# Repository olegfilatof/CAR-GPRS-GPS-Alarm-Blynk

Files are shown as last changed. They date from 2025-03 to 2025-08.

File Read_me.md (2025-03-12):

 Представляю Вашему вниманию «автомобильная сигнализация с функциями удалённого контроля и позиционирования авто». 
 Основные возможности: 
1. Первичные настройки и  контроль за параметрами осуществляются при помощи веб интерфейса, в который можно попасть, используя подключение к Точке Доступа (далее ТД) подключившись к точке доступа MY_AVTO-WIFI, возникающей через 20 сек после подключения питания 12VDC от автомобильного аккумулятора.
2. Основные параметры:
	а) Напряжение аккумулятора, по которому косвенно и сильно не точно можно судить 	о заряде аккумулятора
	б)  Температура в салоне, температура двигателя. 
	в) Координаты GPS авто (необходимо около 10 мин для «холодного старта» при 		    первом запуске устройства)
	г) Состояние датчика вибрации (возможно использование вместо него датчика 		   Холла, герконов, конечных выключателей и т. д., допускается множество 	  		    параллельно соединённых датчиков с NO контактами, с замыканием контактов при 	    срабатывании).
	д) Состояние инфракрасного датчика присутствия  SR505, с задержкой замкнутых 		контактов при срабатывании на  10 сек., для инвертирования сигнала, по требованиям  	правильной 	логики работы устройства, применен обычный маломощный NPN 	транзистор, см. схему. Параллельно допускается использование других датчиков с NO 	контактами, с замыканием контактов при срабатывании).
	е) Состояние двух реле для контроля авто дистанционно. Первое рекомендуется 	применять для аварийной остановки авто, разрывая любые важные для 	функционирования цепи: бензонасос, управление меткой электронного ключа, цепи 	шины CAN и т. д. Контакты второго реле рекомендуется подключить к 	автомобильному клаксону, время работы = 1 мин, с автоматической остановкой. 
	ж) Включатель работы GPS, модема GPRS. 
	з) Изменение пароля ТД 
	и) Изменение периода работы модема, это время паузы между выходами модема на 	     связь. 
	к) Настройка apn sim карты для успешного соединения с сетью Internet. 
Каждое действие в меню обязано завершаться кликом на «Перегрузить устройство с сохранением». 
 Не удалось организовать динамический ввод
 //#define BLYNK_TEMPLATE_ID "jhj"
//#define BLYNK_TEMPLATE_NAME "kgkhjgk"
//#define BLYNK_AUTH_TOKEN "jjh"
так как это противоречит условиям Blynk API.  Кому удастся- прошу дать мне знать об этом. Пользователь обязан вставить свои параметры в код самостоятельно, выбрав в Blynk при создании устрйства: «ESP32» и способ соединения: GSM. 
Логика работы устройства следующая: при подаче питания впервые, начинает через 20 секунд работать ТД. После окончания необходимых настроек, пользователь нажимает «Перегрузить устройство с сохранением». 
После этого включается единственный раз на 2 минуты, - первый запуск после любого Reboot, - ТД с Вашим паролем, сохранённым в контроллере после ввода пользователем. 
 Через 2 мин wifi отключается и запускается модем. 

  Далее вся работа с сигнализацией ведётся через великолепное приложение Blynk, разработанный  украинскими гениями. 
 Мне удалось на бесплатном аккаунте добиться вывода полученных дистанционно координат на карте в браузере, по клику, во всём инете не встречал подобного, одни вопли о 100$ за такую возможность на платном аккаунте.
 После подключения к Blynk и успешного соединения модема с облачным сервисом, в меню Blynk появляются данные. Имеется возможность управления дистанционно. 
 После успешной передачи данных контроллер и вся система уходят в глубокий сон, с энергопотреблением в районе  2 микроампера. Для сравнения, обычная сигнализация без доступа по сети интернет, в стерегущем режиме потребляет около 25mA, на три порядка (!) больше. 
 Время выхода на связь можно задать и из меню Blynk. Рекомендуется 30 — 180 минут. 
В режиме «коннект каждые 30 минут» не удалось выйти за лимит 30000 сообщений бесплатного аккаунта blynk в месяц. Не рекомендуется устанавливать слишком малый интервал из-за высокого энергопотребления модема и неоправданного расхода батареи авто. 
  Привет  тебе, погромист  с  народным платным проектом "GSM автосигнализация" https://www.drive2.ru/c/593248096910065300/ с двумя(!) контроллерами :) и потреблением 150- 200mA постоянно… На мой взгляд, сигнализация, высаживающая заряд автомобильного аккумулятора за неделю  стоянки, — это уже за гранью добра и разума.  
 Не забыты и странные жители тоталитарных стран, с тотальным воровством у ближнего и, как следствие, наличием дополнительной сигнализации в каждом(!) авто. Поэтому предусмотрен аварийный выход из режима сна и выход на связь — при аларме, вызванном срабатыванием любого из сенсоров. При этом каждые 30 сек в течении 2-х минут высылаются  параметры, связанные с охраной авто. Включаются алармы обычной кнопкой при выходе из авто. И я и супруга за ненадобностью такой опции, регулярно забываем о кнопке, да оно и не надо в нормальных странах совершенно… А вот точка на карте, где оставили авто при путешествиях — просто бесценная информация. Вспоминаю, как мы осенью искали час авто без GPS датчика в Праге… :)
 Уведомления о событиях элементарно настраиваются в Blynk, раздел «автоматизация»,  начиная со звукового сигнала в режиме реального времени о событии и заканчивая посылкой сообщения на e-mail. 
 Предложения по усовершенствованию кода, улучшениях в логике работы, благодарностях — приветствуются. 
Disclaymer:  код и схема устройства предоставляются под свободной лицензией и любые претензии к Автору по поводу убытков и неудобств, вызванных попытками изготовления и  использования данного устройства, являются юридически несостоятельными. Автор снимает с себя всякую ответственность за возможные неудобства, материальные убытки и последствия из-за использования продуктов его интеллектуального труда. Ссылка на код, чертежи, промышленное изготовление Устройства возможны  только на условиях  упоминания моего авторства. Искренне Ваш, Олег Филатов. 

Список использованных устройств: 
1. контроллер esp32 Wroom — 1шт. (примерная стоимость 4 Euro
2. DC-DC преобразователь 12VDC- 5VDC, 2A, примерная стоимость 1 Euro
3.  модем SIM800C, выбирайте с питанием 5V только!! И TTL согласованием Rx Tx на плате,  примерная стоимость 3.5 Euro
4. GPS модуль  Neo-6MV2, 3.5 Euro
5. Датчик инфракрасный  SR505, 1 Euro
6. Выключатель алармов, 1 Euro
7. транзистор npn 2N4401, либо любой другой, маломощный NPN транзистор 0.5 Euro
8. 2 транзистора MOSFET IRLB8743, либо другие, надёжно открывающиеся от напряжения выше 2.5VDC (напряжение порта используемого контроллера 3.5VDC) и ток не менее 5A.,
- 2 Euro
9. Резисторы номиналов: 10k — 4шт, 1к -1 шт, 1M — 1 шт, 220К — 1 шт. = 0.5 Euro
10. Реле для Ардуино, 5В — 2 шт, Level HIGH,  2 Euro
11. Датчики DS18B20, Dallas, гильзованные — 2 шт, 2 Euro
12. Геркон с магнитом, 1 шт. — 1E.
Итого: примерно 20 Евро за автосигнализацию с интернет доступом. 
 Для сравнения: средняя сигнализация для авто, с локальным управлением, стоит около 100Euro, с GSM модулем- от 200Euro. Минус удовольствие от творчества… :). 

    1. Лайфхак от меня. Прикупить esim sim карту, самую простую, даже с ограничением на установку только 2-х профилей, например: 5ber, либо 9esim. 
       Находим контору, дающую esim прямо при регистрации, например Betterroaming 
    2. Оплачиваем профиль «Europe Global» за пару евро на год, 1Гб трафика. 
    3. Вставляем в модем, прописываем apn- всё, за символические средства мы видим авто в любой точке Европы целый год. Можно вообще не экономить батарею и настроить систему работать без отключений и сна. Но это уже путь мазохиста- экспериментатора. Алло, мы ищем таланты и отзывы от них! 

Тарифы, к примеру:  esim  от  bnesim на сегодня. Роскошно же. 

Surf 1GB in Europe
1GB
Validity: ∞
No expiry
$2.28
(€2.10)

    Дарю код бесплатно, принимаю благодарности в евро на счёт с реквизитами IBAN:
	 BE95 9741 1406 6858, Oleg Filatov. Bank ID code: PESOBEB1.

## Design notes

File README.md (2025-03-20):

# CAR-GPRS-GPS-Alarm-Blynk
Car alarm remote system with wifi local settings and Blynk web interface. 
 Connection: gprs modem SIM800C. 
 Coordinates: GPS transmitter. 
 Alarms: 2 sensors, InfraRed Human and Vibro sensor.
 Control: 2 relays. Control equipment: motor stop and sound alarm.
 extra sensors: any, NO contacts in parallel with vibro and IR sensors.
 Power supply: 12-14.5VDC from car accumulator battery.
 Power consumption: 0.1 A/h per day. Don't worry about your battery life!
  Connect all electronic elements in accordance with drowings and flash 
  controller. 2 Hours- and you will get 20Euro auto alarm with GPS positioning 
  and controls. Good Luck!

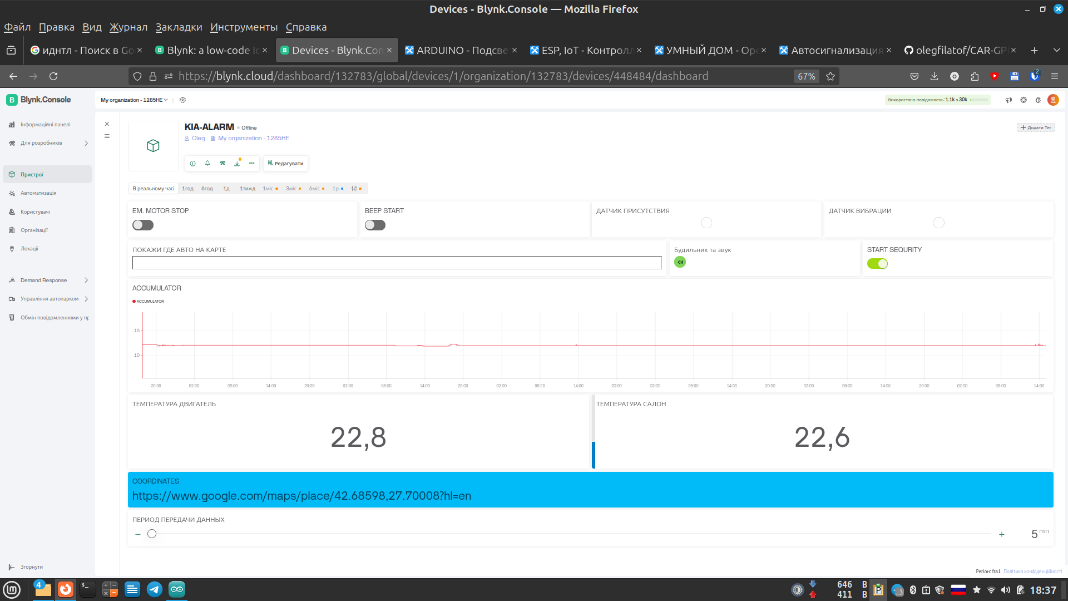
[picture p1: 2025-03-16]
Blynk-full.png

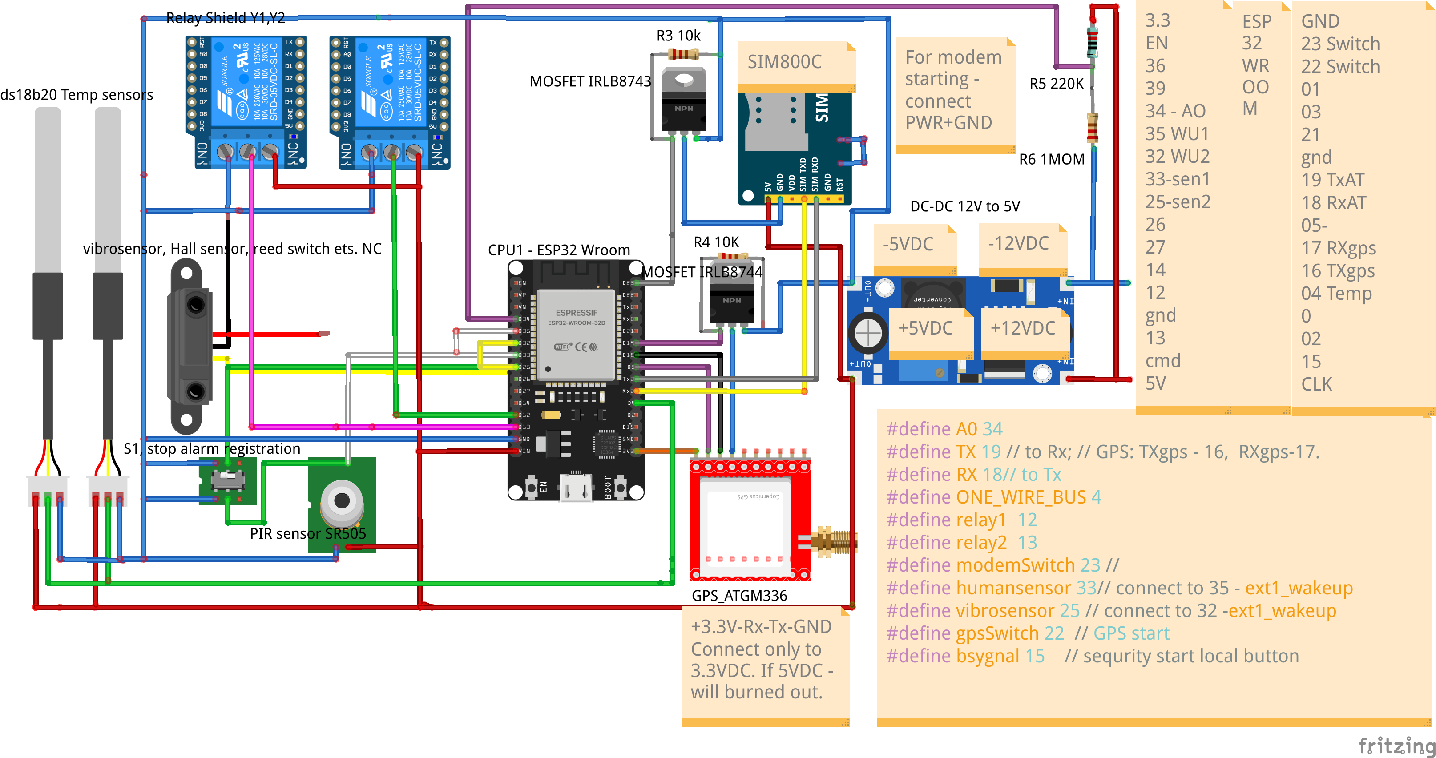
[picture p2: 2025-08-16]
AvtoAlarm_МП.png

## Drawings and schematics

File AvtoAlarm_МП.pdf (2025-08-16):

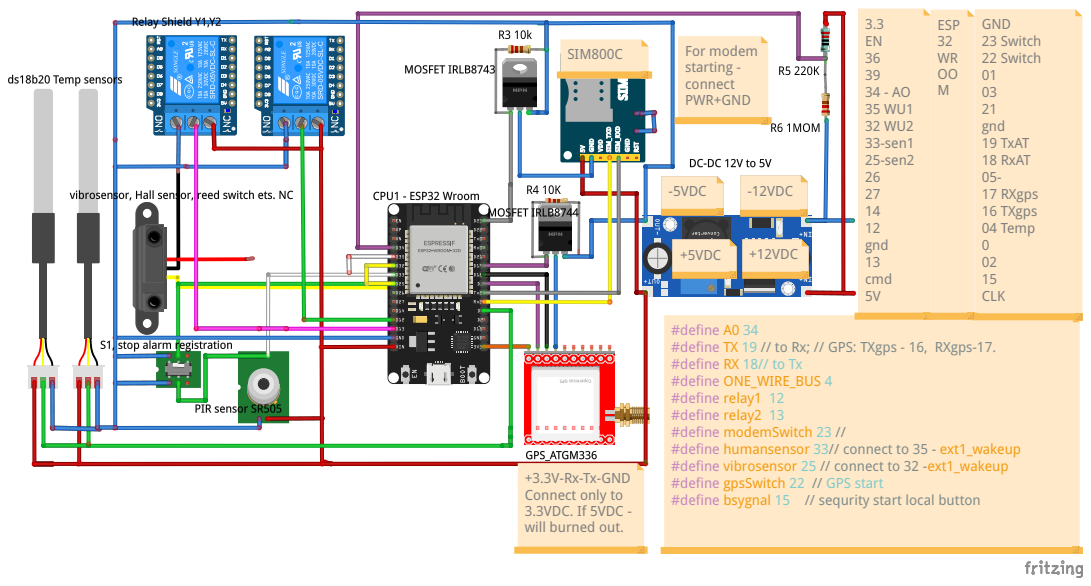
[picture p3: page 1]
For modem starting - connect PWR+GND; -5VDC; 3.3 EN 36 39 34 - AO 35 WU1 32 WU2 33-sen1 25-sen2 26 27 14 12 gnd 13 cmd 5V; GND 23 Switch 22 Switch 01 03 21 gnd 19 TxAT 18 RxAT 05- 17 RXgps 16 TXgps 04 Temp 0 02 15 CLK; ESP 32 WR OO M; +12VDC; -12VDC; +5VDC; SIM800C

#define A0 34
#define TX 19 // to Rx; // GPS: TXgps - 16, RXgps-17.
#define RX 18// to Tx
#define ONE_WIRE_BUS 4
#define relay1 12
#define relay2 13
#define modemSwitch 23 //
#define humansensor 33// connect to 35 - ext1_wakeup
#define vibrosensor 25 // connect to 32 -ext1_wakeup
#define gpsSwitch 22 // GPS start
#define bsygnal 15 // sequrity start local button

+3.3V-Rx-Tx-GND
Connect only to
3.3VDC. If 5VDC -
will burned out.

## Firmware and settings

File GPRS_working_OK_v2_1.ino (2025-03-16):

//OK for ESP32 Dev Module
/* Comment this out to disable prints and save space */
#define BLYNK_PRINT Serial
//-----------------------------------------------------------------------
#define BLYNK_TEMPLATE_ID           "TMPL4fa-kn3Dz"
#define BLYNK_TEMPLATE_NAME         "CAR GPS"
#define BLYNK_AUTH_TOKEN            "HDl45JpsYRZgO3nOyNjqZLBxPqDeuFlx"
// You should get Auth Token in the Blynk App.
// Go to the Project Settings (nut icon).
//char auth[] = BLYNK_AUTH_TOKEN;
//============================================

bool modemStartingF = false;
int sleepTime = 3; // для задачи периода сна, в минутах!!!
bool firstTime = true; // флаг для однократного запуска wifi в 1-й раз

//============================================

#include "initiation.h"
#include "settingsInit1.h"
bool sequrityStart = true; // по умолчанию охрана включена
static bool flag = false;

void SendData() {
  if (alarmON and sequrityStart) {
  //если выходит на связь по программе- отправлять 1 раз координаты, voltage, temperatures. Если сработал alarm- 
  // каждые 30 сек высылается состояние датчиков в течении 3 мин 
    Blynk.virtualWrite(V20,alarmHF);
    Blynk.virtualWrite(V21,alarmVF);
    Blynk.virtualWrite(V13,alarmON); //звуковой сигнал
    //Blynk.virtualWrite(V13,alarmON); //звуковой сигнал
     //  coordinates = "https://www.google.com/maps/place/"+String(latitude,8)+","+String(longitude,8)+"?hl=en";
 // url = "https://www.google.com/maps/place/"+String(latitude,6)+","+String(longitude,6)+"?hl=en"; //ОК
         // real GPS////////////
      gps.read();
  url = "https://www.google.com/maps/place/"+String(gps.latitude,5)+","+String(gps.longitude,5)+"?hl=en"; //ОК 
//////////////////////

  Blynk.virtualWrite(V7, url); // Отправляем динамический URL на V7
  Blynk.virtualWrite(V27, flag); // Отправляем динамический URL на V27
  Blynk.setProperty(V27, "url", url);
  Serial.print("Отправил данные алармов из SendData, alarmHF=   "); Serial.println(alarmHF); 
  Serial.print("Отправил данные алармов из SendData, alarmVF=   "); Serial.println(alarmVF); 
  }}
  

void setup()
{
  // Debug console
  Serial.begin(115200);

  // используем метод ext1 для пробуждения по уровню на портах, понадобится вот эта строчка: 
  esp_sleep_enable_ext1_wakeup(pinBitMask,ESP_EXT1_WAKEUP_ANY_HIGH);
//  ESP_EXT1_WAKEUP_ALL_LOW: wake up when all GPIOs go low; - если ВСЕ порты... 
//  ESP_EXT1_WAKEUP_ANY_HIGH: wake up when any of the GPIOs go high. -любой порт из указанных
//If you’re using an ESP32-S2, ESP32-S3, ESP32-C6 or ESP32-H2, these are the available modes:
//ESP_EXT1_WAKEUP_ANY_LOW: wake up when any of the selected GPIOs is low
//ESP_EXT1_WAKEUP_ANY_HIGH: wake up when any of the selected GPIOs is high

  pinMode(relay1,OUTPUT);
  pinMode(relay2,OUTPUT);
  pinMode(modemSwitch,OUTPUT);
  pinMode(gpsSwitch,OUTPUT);
  pinMode(humansensor,INPUT_PULLUP); humansensorI.setDebounceTime(50);
  pinMode(vibrosensor,INPUT_PULLUP); vibrosensorI.setDebounceTime(50); 
  //pinMode(bsygnal,OUTPUT);  bsygnalI.setDebounceTime(50); 
//после выхода из сна ножка (ножки) IO, которая используется для пробуждения, может быть сконфигурирована как RTC IO. 
//Перед использованием этой ножки в качестве digital GPIO переконфигурируйте её с помощью функции rtc_gpio_deinit.
  
  digitalWrite(relay1,0);
  digitalWrite(relay2,0);
  digitalWrite(modemSwitch,0);
  digitalWrite(gpsSwitch,0);
  //digitalWrite(2,0); 
  pinMode(intLed,OUTPUT);
  digitalWrite(intLed,0); // onboard LED stop

  delay(10);

#include "setup1.h"
#include "settingsSetup2.h"
////////////////////////////////////////////////////////////////////////////////////////////////////////////


startGPSF = db[dataBase::startGPS]; // флаг включения GPRS
   // узнаём, в каком состоянии переменные в базе данных:
   // если строка с APN заполнена - читаем оттуда apn, иначе - смотри строку 37 initiation.h, там якобы универсальный APN 
if (db[dataBase::sim_APN].length()) { apn = db[dataBase::sim_APN].toString(); } // кому не нравятся тут {} - может удалить самостоятельно, я не возражаю :)


//if (db[dataBase::GPS_interval_send].length()) {sleepTime = db[dataBase::GPS_interval_send].toInt64(); } // интервал в микросекундах, загрёбся я переводить эту хрень в нужный формат... 
// else {sleepTime = 30;} // 30 минут - интервал выхода на связь и посылка данных в blynk, если режим экономии батареи
sleepTime = db[dataBase::GPS_interval_send].toInt64(); 
relay1F = db[dataBase::engineStop];
relay2F = db[dataBase::beepStart];
batteryF = db[dataBase::saveBattery];

  
/////////////////////////////////////////////////////////////// 

  // вызываем таймер отправки в blynk по времени if (wifiStart1time) { wifiStart1time = false; Wificonnection(); } 
  timer.setInterval(INTERVAL, SendData);
  //-----------------------------------------------------------  
///////////////////////////////////////////////////////////////
 /*
  wifiStart1time = true;
  if (wifiStart1time) // исли 1-й раз стартуем - старт wifi,  wifiStart1time == true
  { if (startGPSF) {TimerModemStart.start();} // если включён GPRS в настройках- старт модем через 2 мин после старта wifi
  
  // если нет - wifi продолжает работать всё время и аккамулятору капут через неделю
  
  { wifiStart1time = false;  Wificonnection();  } 
  }
  // если это уже второй запуск, после сна, то wifi не включается, а сразу модем, без паузы на wifi:
  else { WifiStop(); ModemStart(); modemStartingF = true; TimerModemStop.setTimeout(120000);}
  
  // если не нажато "Старт GPS, стоп wifi, экономим заряд батареи", то wifi не отключает соединение, модем не стартует, в сон не впадаем
//даём wifi подключиться, затем таймер сработает- и пипец тому wifi, GPRS рулит необычвйно

 //если включён старт gprs в settings морде- стартуем модем через 120 сек и стоп wifi если 1-й запуск,
 //если запуск после сна - стразу старт модем. 
*/

if (startGPSF and wifiStart1time) { TimerModemStart.setTimeout(120000); } // в первый раз - пауза на работу wifi 2 min, затем- модем, если включён в настройках

if (startGPSF and wifiStart1time == false) { ModemStart(); modemStartingF = true; TimerModemStop.setTimeout(120000);} //Если не 1-й раз - модем запускаем сразу 

if (wifiStart1time) { Wificonnection(); loopData = true; } // запускаем в первый раз, потом включается wifiStart1time = false; в функции
// если заснёт -  усё, потом нет wifi-я, зая!. Если перезагрузить - ок, wifi первые 2 минуты + web морда вайфайная, либо wifi всегда, если не запущен GPS в вэбморде

// включаем через 2 минуты модем, если включён в web морде startGPS, выключается автоматически  wifi.
// иначе - пипец заряду аккумулятора через 10 дней, привет тебе, погромист,
// с проектом "GSM автосигнализация" https://www.drive2.ru/c/593248096910065300/ с двумя(!) контроллерами :) и потреблением 150mA постоянно...

//-----------------------------------------------------------
 // Serial.print("startGPSF = " ); Serial.println(startGPSF);
 // Serial.print("apn = " ); Serial.println(apn);
 // Serial.print("sleepTime = " ); Serial.println(sleepTime);
 // Serial.print("relay1F = " ); Serial.println(relay1F);
 // Serial.print("relay2F = " ); Serial.println(relay2F);
 // Serial.print("batteryF = " ); Serial.println(batteryF);
 // Serial.print("wifiStart1time = " ); Serial.println(wifiStart1time);
 //Serial.print("sequrityStart = " ); Serial.println(sequrityStart);
}
 
/**********************************************************************************
 *  loop() function
 **********************************************************************************/
void loop()
{
  
  if (TimerModemStart.isReady()) { WifiStop(); loopData = false; ModemStart(); modemStartingF = true; TimerModemStop.setTimeout(120000);}  

  if (modemStartingF) { Blynk.run();  timer.run();  }
     
  if (TimerModemStop.isReady()) { modemStartingF = false; ModemStopping();  } //Serial.println("сработал таймер сна ");
  
  sett.tick(); //3 settings in loop
  
  #include "loop3.h"

/*
    static unsigned long timerGPS;
  if (millis() - timerGPS >= 2000) {
    timerGPS = millis();
       gps.read();
  url = "https://www.google.com/maps/place/"+String(gps.latitude,5)+","+String(gps.longitude,5)+"?hl=en"; //ОК 
  Serial.println(url);
  }
*/
}
//////////// Лупец finish ///////////////////////////////////////////////
 
 BLYNK_WRITE(V1) // From Blynk to the ESP32, to control a Relay1
  {
  int pinValue1 = param.asInt();
  digitalWrite(relay1 , pinValue1);
  
  }
     BLYNK_WRITE(V2) // From Blynk to the ESP32, to control a Relay2
  {
  int pinValue2 = param.asInt();
  digitalWrite(relay2 , pinValue2); 
  }

       BLYNK_WRITE(V3) // From Blynk to the ESP32, to control a Relay2
  {
  int sequrityStart = param.asInt(); // assigning incoming value from pin V1 to a variable
  
  }

  BLYNK_WRITE(V28)
  {
  int sleepTime = param.asInt(); // assigning incoming value from pin V1 to a variable
  // You can also use: String i = param.asStr();  double d = param.asDouble();
  //Serial.print("V28 Slider value is: ");
  //Serial.println(sleepTime);
  db[dataBase::GPS_interval_send] = sleepTime; db.update(); // ХЗ, с этими update, никогда не удавалось с ходу понять логику Gyver... :)
  }

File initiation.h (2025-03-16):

#include "GyverTimer.h"              // библиотека таймера
//Timer Timer1month(MS, 2592000000); // (86400000×30 суток)ms для однократного срабатывания
GTimer TimerModemStart(MS); // 
GTimer TimerModemStop(MS); // 

GTimer Timer2minWIFI(MS); // cтоп wifi после 2 мин. работы
GTimer Timer3minModemON(MS); //время работы модема

GTimer Timer1minH(MS); // сработал датчик human - 1 мин аларм
GTimer Timer1minV(MS); // сработал датчик vibro - 1 мин аларм

GTimer Timer30sec1(MS); // сработала кнопка stop motor - 30 сек аларм
GTimer Timer30sec2(MS); // сработала кнопка старт бибикалка - 30 сек аларм

//GTimer Timer1sec(MS);

//TimerModemStart.setTimeout(120000);   // настроить таймаут 120 сек и запустить (перезапустить) таймер
//if (TimerModemStart.isReady()) Serial.println("Timeout 120сек сработал!");
//TimerModemStart.stop();   // "остановить" таймер
//myTimer.setTimeout(3000);   // настроить таймаут 3 сек, затем - стоп без условий
//----------------------------------------------------------------------
#define VREF 1.0328 // VREF = 1.1V в ESP32, но тут надо с вольтметром в руках прикидывать поправку, от множества факторов зависят измерения, 
// причём, слухи о "лютой нелинейности АЦП esp" - неуместны. :).
// 1.04 - 12.00; 1.034 - 11.94; 1.032 - 11.90

// Измерение Напряжения
// GND -- [ R2 ] -- A0 -- [ R1 ] -- VIN  + 0.1 mkF конденсатор на GND и порт A0
#define DIV_R1 1000000  // точное значение 1000 кОм резистора (1 MOM)
#define DIV_R2 220000   // точное значение 220 кОм резистора

#define A0 34 // Это порт аналогового сигнала от делителя напряжения аккумулятора
//----------------------------------------------------------------------
// Select your modem:
#define TINY_GSM_MODEM_SIM800
//#define TINY_GSM_MODEM_SIM900

//-----------------------------------------------------------------------
// Default heartbeat interval for GSM is 60
// If you want override this value, uncomment and set this option:
#define BLYNK_HEARTBEAT 185 // больше времени соединения, чтоб не пересоединялся каждые 30 сек
//-----------------------------------------------------------------------
#include <TinyGsmClient.h>
#include <BlynkSimpleTinyGSM.h>
//-----------------------------------------------------------------------
// Your GPRS credentials
// Leave empty, if missing user or pass
String (apn) = "internet";
char user[] = "";
char pass[] = "";
//-----------------------------------------------------------------------
#include <iarduino_GPS_NMEA.h>                     //  Подключаем библиотеку для расшифровки строк протокола NMEA получаемых по UART.
#include <iarduino_GPS_ATGM336.h>                  //  Подключаем библиотеку для настройки параметров работы GPS модуля ATGM336.
                                                   //
iarduino_GPS_NMEA    gps;                          //  Объявляем объект gps         для работы с функциями и методами библиотеки iarduino_GPS_NMEA.
iarduino_GPS_ATGM336 SettingsGPS;                  //  Объявляем объект SettingsGPS для работы с функциями и методами библиотеки iarduino_GPS_ATGM336.
/////////////////////////////////////////////////////////////////////////////////////////////////////////
//Modem:
#define RXmodem 18 // 
#define TXmodem 19 // 

//GPS
#define RXgps 17 //
#define TXgps 16 //   
#define GPS_BAUD 9600  // обязательно.  на скорости 115200 - не работает!

HardwareSerial gpsSerial(1);
HardwareSerial SerialAT(2);
#define gpsSerial Serial1
#define SerialAT Serial2


TinyGsm modem(SerialAT);
//TEMPERATURE SENSORS-----------------------------------------------------
#include <OneWire.h>
#include <DallasTemperature.h>
// Setup a oneWire instance to communicate with any OneWire devices
#define ONE_WIRE_BUS 4
OneWire oneWire(ONE_WIRE_BUS);
// Pass our oneWire reference to Dallas Temperature sensor 
DallasTemperature sensors(&oneWire);
//________________________________________________________________________
#define intLed 2 // светодиод blue onboard, надо погасить, шоб не ел ток аккумулятора
#define relay1  12
#define relay2  13
#define modemSwitch 23 // выключатель модема
#define humansensor 33 // объединить с 35
#define vibrosensor 25 // объединить с 32 
//#define bsygnal 15// сигнал с сервера о постановке на охрану, pin V3 на сервере, либо физически замкнута кнопка T1
#define gpsSwitch 22 // выключатель GPS
//----------
float temp1; // pin 4
float temp2; // pin 4
//float longitude;
//float latitude; 
String coordinates;
int humanSt = 0;
int vibroSt = 0;
bool alarmHF; 
bool alarmVF;
//int bsygnalSt = 0;
bool alarmON = false;
String Temp1;
String Temp2;
float voltage;
bool sequrityStartF;
String url;
bool loopData;
// Save reading number on RTC memory
RTC_DATA_ATTR bool wifiStart1time = true;  // смотри функцию Wificonnection() { if (wifiStart1time) {wifiStart1time = false;} 
//-----------------------------------------------------------------------
BlynkTimer timer;
#define INTERVAL 30000L // интервал отправки данных при подключенном модеме
//-----------------------------------------------------------------------

//#define humanSensor  39 // датчик присутствия // уже указан в маске 35
//#define vibroSensor  34 // датчик вибрации   // уже указан в маске  32

//////////////////////////
//Режим глубокого сна и внешнее пробуждение
//В качестве инициатора внешнего пробуждения могут использоваться только контакты типа RTC_GPIO. Вот они: 
//ESP32: 0, 2, 4, 12-15, 25-27, 32-39 //ESP32-S2: 0-21 //ESP32-S3: 0-21 //ESP32-C6: 0-7 //ESP32-H2: 7-14

// Пробуждение, если любая из выбранных ножек находится в лог. 1 (ESP_EXT1_WAKEUP_ANY_HIGH).
// Пробуждение, если любая из выбранных ножек находится в лог. 0 (ESP_EXT1_WAKEUP_ALL_LOW).
//сделал битовый флаг не как у индуса, с маятой и мутью, а грамотно: 
int WakeUppin, wakeFlag = 0;
constexpr uint8_t humanSensor = 35;
constexpr uint8_t vibroSensor = 32;
constexpr uint64_t humanSensorBitFlag = (static_cast<uint64_t>(1) << humanSensor);
constexpr uint64_t vibroSensorBitFlag = (static_cast<uint64_t>(1) << vibroSensor);
constexpr uint64_t pinBitMask = (humanSensorBitFlag | vibroSensorBitFlag);
void print_GPIO_wake_up(){
   WakeUppin = log(esp_sleep_get_ext1_wakeup_status())/log(2);
  Serial.print("WakeUppin = "); Serial.println(WakeUppin); 
  if (WakeUppin == humanSensor) {  wakeFlag = 1; Serial.println("Сработал humanSensor");}
  if (WakeUppin == vibroSensor) {  wakeFlag = 2; Serial.println("Сработал vibroSensor");}
 // if (WakeUppin == newSensor) {  wakeFlag = 3; Serial.println("Сработал newSensor");}
}
////////////////////////////////////////////////////////////////////////////////////////////
 #include <ezButton.h>
ezButton humansensorI(humansensor); 
ezButton vibrosensorI(vibrosensor);
ezButton relay1I(relay1);
ezButton relay2I(relay2);
////////////////////////////////////////////////////////////////////////////////////////////
